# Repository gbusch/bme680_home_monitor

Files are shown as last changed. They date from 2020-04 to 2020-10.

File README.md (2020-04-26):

# Indoor air quality monitoring
From (indoor air quality) measurement to dashboard without any manual configuration.

## Table of contents
* [Goal](#Goal)
  * [Additional technical requirements](#Additional-technical-requirements)
* [Realization](#Realization)
  * [Measuring and sending data with the ESP32](#Measuring-and-sending-data-with-the-ESP32)
  * [Processing, storing, and displaying data on the Raspberry Pi](#Processing,-storing,-and-displaying-data-on-the-Raspberry-Pi)
  * [Compiling the protocol buffers](#Compiling-the-protocol-buffers)
* [Shopping list](#Shopping-list)
* [How to get started](#How-to-get-started)

## Goal
My goal was to monitor temperature, humidity and indoor air quality (IAQ) in our apartment and display it in a dashboard which should be accessible from within our home network.

### Additional technical requirements
Additional requirements, which were mostly not practically necessary but rather added for educational purposes, where:
* communication between microcontroller and Raspberry Pi with MQTT
* MQTT messages are encoded in protocol buffer (protobuf) format
* software on microcontroller should be fully version controlled, including dependencies
* software on Raspberry Pi should be fully version controlled as well, including all configurations, and all software should be started with one command.

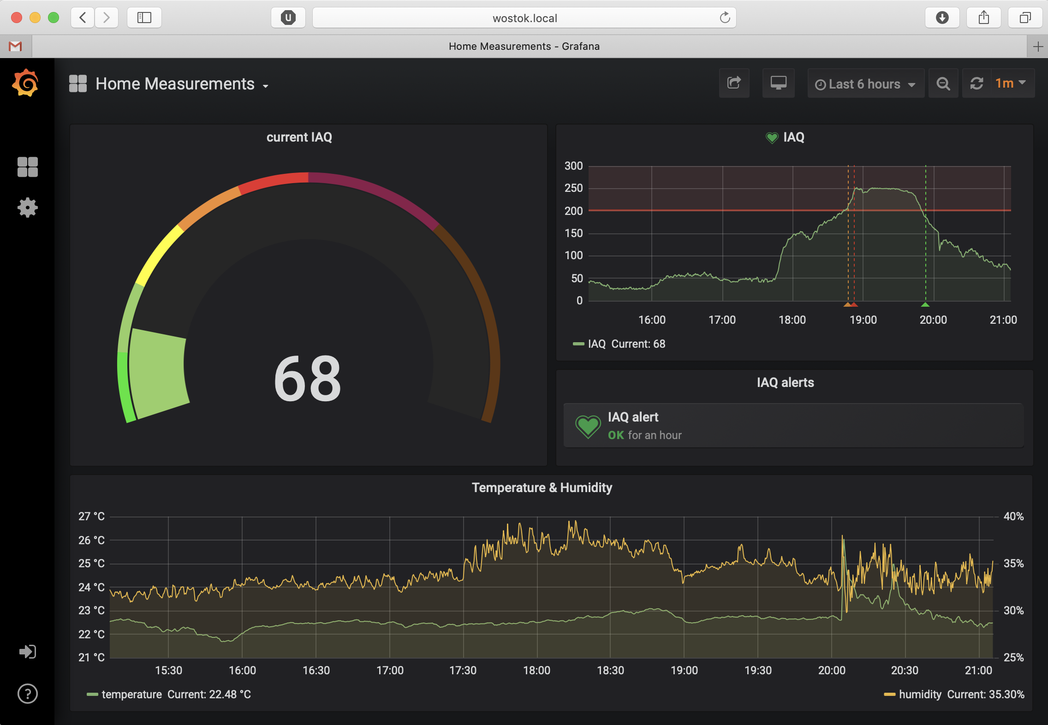
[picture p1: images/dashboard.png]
screenshot of dashboard missing


## Realization
This was realized with a BME680 sensor from Bosch connected to a ESP32 which is a powerful microcontroller with, amongst others, wifi connectivity. The backend and frontend run on a Raspberry Pi 3B+. As frontend we use Grafana which also allows for alerting, for example as Telegram notifications on the smart phone. The Grafana dashboard can be accessed from all devices which are connected to the home wifi network.

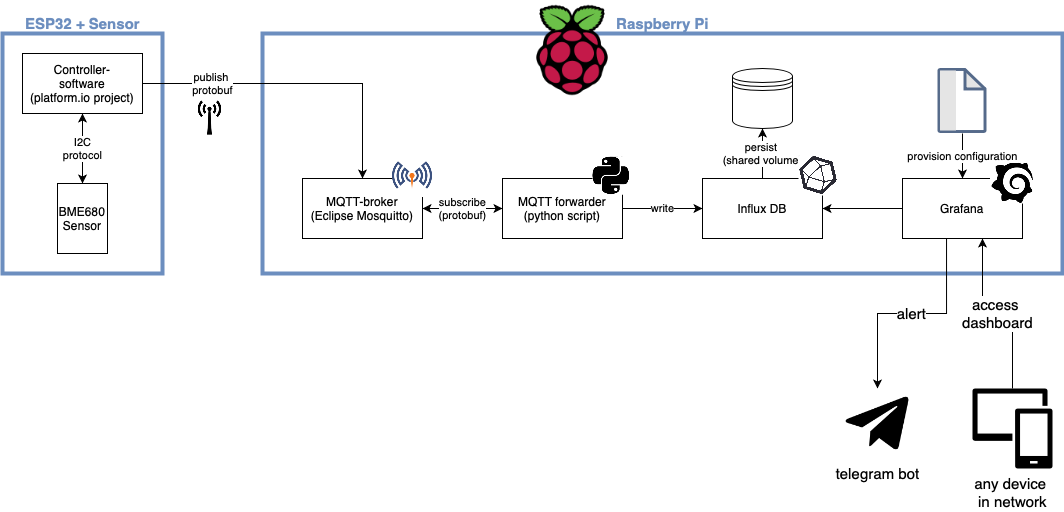
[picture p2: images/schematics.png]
image missing Schematics


### Measuring and sending data with the ESP32
The manufacturer of the BME680 sensor provides a library for several controllers, including the ESP8266/ESP32. In contrast to other open-source libraries for the BME-sensor series, the so-called BSEC library includes a self-calibration of the indoor air quality sensors.

The scripts provided were augmented with additional functionality for this project:
* connection to the home wifi, using the standard wifi library for ESP32
* connection and publishing to an MQTT-broker using the pubsub-client library
* encoding of messages to protocol buffers using the nanopb library (more details on protocol buffers below).

PlatformIO was used to program the ESP32. This platform does not only offer the comfort of an IDE (e.g. code completion) but also dependency management. This is a huge improvement compared to Arduino IDE where dependencies are usually installed manually and stored globally. Here, the dependencies are tracked per project which allows to include them into version control and they are installed automatically when building the project. 

Software for the ESP32 is provided in the [esp32_bme680](./esp32_bme680/) folder, detailed instructions can be found in the associated [README](./esp32_bme680/README.md).

### Processing, storing, and displaying data on the Raspberry Pi
The measurements that the ESP32 sent as protobuf-encoded MQTT messages, are then processed, stored and displayed using different software components:
* Eclipse Mosquitto as MQTT broker. The ESP32 publishes messages to a specific topic. Other programs can now subscribe to this topic and receive the messages. The MQTT broker is accessible within the home network and can be used for other projects as well.
* A MQTT forwarder script. A simple python script that subscribes to the MQTT topic, decodes all received messages and stores them in a database.
* An InfluxDB databse where the measurements are stored. A shared volume ensures that the data is persisted when the docker container is shutdown or restarted.
* Grafana which is a dashboarding and monitoring tool. The data is displayed in a dashboard that is accessible in a browser from all devices in the network. Furthermore, notifications can be sent, in this example via the Telegram messaging app. Grafana offers provisioning which means that all configuration, including the dashboard definition, is provided in files and no manual configuration is necessary. 

All these components are running as Docker containers on the Raspberry Pi. Using docker-compose, the whole stack can be started with one single command. Running them as Docker containers offers many advantages:
* Preconfigured Docker containers are provided for most open-source projects so that no manual installation is necessary.
* Configuration can be documented and version-controlled using the docker-compose file.
* Dependencies are automatically handled.
* Everything can be started (and shut down) with one command.

Software and more detailed instructions on how to set it up on the Raspberry Pi can be found in the directory [raspberrypi](./raspberrypi/) and the corresponding [README](./raspberrypi/README.md).

### Compiling the protocol buffers
As mentioned before, the messages that are sent from the ESP32 are encoded as protocol buffers. Protocol buffers (short: protobuf) are a language- and platform-neutral mechanism for the serialization and deserialization of structured data. They were developed by Google to be simpler, smaller, faster and easier to maintainer than XML, but even surpass JSON in their performance.

While it is considerably easy to define the message format (see [data.proto](esp32_bme680/src/data.proto)), these proto-files then have to be compiled for each language that they should be used with. Support for several languages, including python, is provided with Google's compiler. Support for other languages is added by the community, namely nanopb for embedded devices like our ESP32.

*Good news is: As long as you do not want to change the message format, there is nothing you have to do as the needed compiled files are included in the repo.*

Note that if, for any reason, you want to change the message format, you need to:
* compile it for the ESP32 (with nanopb) and for the MQTT Forwarder (python)
* change the part where the message is encoded in [main.cpp](esp32_bme680/src/main.cpp) and where it is decoded in [python-listener.py](raspberrypi/mqtt-forwarder/python-listener.py)
* delete the existing InfluxDB database or use a new one in case the schema changes in this process.

The base-compiler protoc as well as nanopb can be installed locally. However to avoid trouble with dependencies, it might be worth considering a dockerized version. You can find more information on the docker image and how to use it on [DockerHub](https://hub.docker.com/repository/docker/buschg/protobuf-compiler/general) (you need a DockerHub account) or [GitHub](https://github.com/gbusch/protobuf-compiler).

## Shopping list
Here is a short overview of the parts that you will need:
* The BME680 sensor from Bosch Sensortec. You probably want to get a breakout board. I got the one from BlueDot. A soldering iron was needed to solder the 6-pin header to the board. There might be boards on the market that have the header already attached. Cost: around 20 €. (If you are not interested in indoor air quality but only temperature and humidity you might want to check out the BME280 which is available for less than 5 €.)
* An ESP32 microcontroller. I used the ESP32 Dev Kit C from az-delivery.de but there are many different versions on the market that should work as well. A ESP8266 can also be used but I failed to fully program it with platformIO without any manual modifications. Cost: around 10 €.
* Jumper wires (female-female) to connect ESP32 and sensor.
* A micro-USB charger to power the ESP32.
* A Raspberry Pi with (micro) SD card and power supply. I got an ABOX (now LABISTS) Raspberry Pi 3B+ starter kit which also contained case, power supply, heat sinks and SD card. Cost: around 85 € (A bare Raspberry Pi costs only half, but I recommend to get one proper kit since you can use it for many other projects at the same time as well).

## How to get started
* Get the parts from the shopping list
* Follow [this description](./esp32_bme680/README.md) to connect the sensor and upload the software to the ESP32. Each time serial output is printed, the LED of the ESP32 blinks. For that reason most ```Serial.println()``` are commented out in the script. You might want to use these statements at first for debugging.
* Follow [this description](./raspberrypi/README.md) to setup the Raspberry Pi.
* You can now point your browser to ```http://<address of your raspberry pi>:3000/d/kpBr4Nzgz/home-measurements?orgId=1``` to see your measurements in a dashboard.

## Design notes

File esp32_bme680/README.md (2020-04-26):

# Setting up the sensor and microcontroller

* Install platform.io (instructions can be found on the [project's webpages](https://platformio.org))

* If you use the ESP32 for the first time, you might need to install USB drivers. My ESP32 board uses a CP2102 USB serial communication interface module for which drivers are provided by Silicon Labs.

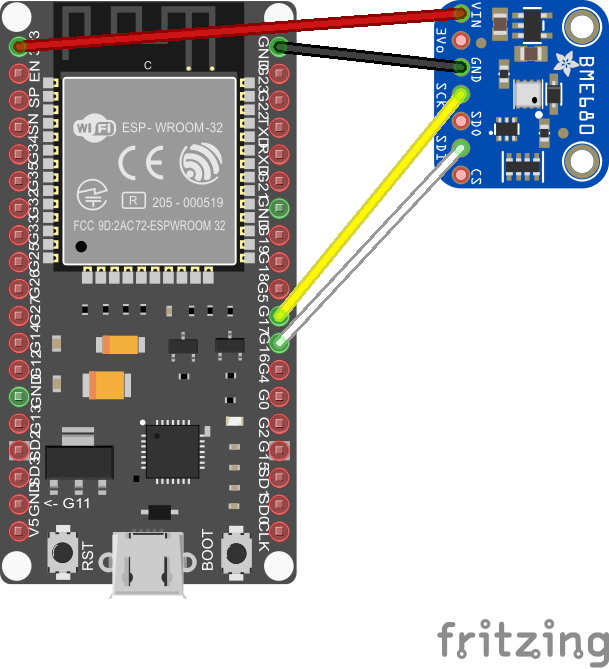
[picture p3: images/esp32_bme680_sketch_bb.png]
image missing sketch
* Connect the sensor and microcontroller as indicated in the sketch. 

* Import the directory esp32_bme680 as a new project into platform.io.

* Create a file include/credentials.h and insert your credentials for wifi and MQTT broker (the address of your raspberry pi). The expected schema is shown in the file [credentials.h.example](include/credentials.h.example).

* You can now upload the project to the ESP32 using platform.io.

*Note: Most software in this folder, including the precompiled library, is provided by Bosch Sensortec and only slightly modified. All rights remain at Bosch Sensortec.*

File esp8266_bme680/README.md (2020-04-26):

# Code for ESP8266 (deprecated)

At first, I used an ESP8266 microcontroller. The code that I used can be found in this directory. However, here the Arduino IDE is used to flash the controller (note the *.ino file). 

I tried to switch to platform.io since this allows to include all dependencies as well. Unfortunately, there was still manual configuration necessary. Namely, the linker script had to be adjusted as described [on the library's Github page](https://github.com/BoschSensortec/BSEC-Arduino-library#4-additional-core-specific-modifications). After many (unsuccessful) tries to include a modified version of this linker script in the project, I decided to switch to an ESP32 where the configuration with platform.io is straight-forward.

If you want to use an ESP8266, these files might help but they will not work straight away. More information on how to get the BSEC software running on ESP8266 can be found [on the library's github page](https://github.com/BoschSensortec/BSEC-Arduino-library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).

Please note that the protobuf message format has changed in the meantime and has to be adjusted (in the mqtt-forwarder).

Also you will have to add your network configuration in [esp8266_bme680.ino]():
```C
const char* ssid = ## your wifi name here ##;
const char* password = ## your wifi password here ##;
const char* mqttServer = ## your MQTT brokers (raspberry pi) address ##;
const int mqttPort = 1883;
```

*Note: Most software in this folder is provided by Bosch Sensortec and only slightly modified. All rights remain at Bosch Sensortec.*

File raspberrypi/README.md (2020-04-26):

# Setting up the Raspberry Pi

## Installation

* Set up your Raspberry Pi with a Linux operating system (e.g. Raspbian) and login (either directly or via ssh). Explaining how to do that is out of scope. However, there are plenty of resources online.

* The following lines have to be executed to install docker. The last line confirms that the installation was successful.
```bash
curl -fsSL get.docker.com -o get-docker.sh && sh get-docker.sh
sudo usermod -aG docker pi
sudo reboot
docker run hello-world
```

* Then install docker-compose. The last line prints out the docker-compose version which confirms a successful installation.
```bash
sudo apt-get install -y python3-pip python3-dev
sudo pip3 install docker-compose
docker-compose --version
```

* You should now clone this repo ```git clone https://github.com/gbusch/bme680_home_monitor.git``` and change to the raspberrypi folder: ```cd bme680_home_monitor/raspberrypi```.

* Now you need to run the build command: ```docker-compose build```. You need to run this command only once and after changes in the mqtt-forwarder.

* Start the docker containers with ```docker-compose up -d```. 

* If you want to stop the containers later, you can do that with ```docker-compose down```.

## Docker containers
The following docker containers will be started:
 
### MQTT-broker (Eclipse Mosquitto)
Eclipse Mosquitto is a light-weight MQTT broker. 
You can use the MQTT broker for other projects as well. Just choose a different topic to publish on.
It will be available in the home network under the address of your Raspberry Pi (since it is in the local network the IP address should start with 192.168.178.*) and port 1883. This is the default port for unencrypted MQTT.

### Database (InfluxDB)
InfluxDB is a database specially suited for timeseries data. The data is stored in the directory ```/var/lib/influxdb```. This folder is mounted to the directory ```./influxdb/data``` on the host machine. This allows to keep data also when the docker-container is shutdown.

### Dashboard (Grafana)
Grafana is an open-source dashboard and monitoring tool. It is accessible from the browser under ```<address of your Raspberry Pi>:3000```. A powerful feature in the newest versions is provisioning. This allows to save the dashboards as well as configuration for data sources and notifications in json and yaml files and provide them to Grafana when the container is started. This way, dashboards can be easily shared and version-controlled together with the project.

The example dashboard will automatically be loaded when the docker containers are started and is accessible in the browser under ```<address of your Raspberry Pi>:3000/d/kpBr4Nzgz/home-measurements?orgId=1```.

#### Changing the dashboard
* Sign in to Grafana using the credentials provided in the [docker-compose.yml](docker-compose.yml) (at the moment admin/secret-password).
* Adjust the dashboard
* Click save. You cannot save a provisioned dashboard from the Grafana UI, instead choose "copy JSON to clipboard". Copy this into the file [./grafana/dashboards/home_measurements.json](./grafana/dashboards/home_measurements.json) and save.
* Next time you restart the container, the new version will be provisioned.

#### Setting up a telegram alert
Grafana also offers alerting and supports many different notification channels. As an example, I configured an alert that is raised whenever the indoor air quality exceeds a value of 200. 

With the following steps, you can configure notifications to Telegram when this alert is raised:

* Create a new bot as described in the [Telegram Documentation](https://core.telegram.org/bots#6-botfather). Note down the bot token.
* Create a telegram group with people that should be alerted and invite the bot to this group.
* Use curl or place this in a browser: ```https://api.telegram.org/bot<TOKEN>/getUpdates```.
* The response returns a json object in which you find the key "chat". Note down the number after "id" (including the dash).
* You can find an example configuration in [./grafana/provisioning/notifiers/telegram.yml.example](./grafana/provisioning/notifiers/telegram.yml.example). Remove the file-ending ".example" and insert bot token and chat id.
* Restart Grafana.

### MQTT forwarder script
This simple python script subscribes to the same topic that the ESP32 publishes to and writes all messages that it receives into the InfluxDB database. The script runs in a Docker container as well so that you do not need to worry about python configuration or the like.

Please note that the first time you use it and whenever you make changes to the script you need to rebuild the container with ```docker-compose build```.

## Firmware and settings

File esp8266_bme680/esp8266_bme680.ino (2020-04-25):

/*
 * Copyright (C) 2017 Robert Bosch. All Rights Reserved. 
 *
 * Disclaimer
 *
 * Common:
 * Bosch Sensortec products are developed for the consumer goods industry. They may only be used
 * within the parameters of the respective valid product data sheet.  Bosch Sensortec products are
 * provided with the express understanding that there is no warranty of fitness for a particular purpose.
 * They are not fit for use in life-sustaining, safety or security sensitive systems or any system or device
 * that may lead to bodily harm or property damage if the system or device malfunctions. In addition,
 * Bosch Sensortec products are not fit for use in products which interact with motor vehicle systems.
 * The resale and/or use of products are at the purchasers own risk and his own responsibility. The
 * examination of fitness for the intended use is the sole responsibility of the Purchaser.
 *
 * The purchaser shall indemnify Bosch Sensortec from all third party claims, including any claims for
 * incidental, or consequential damages, arising from any product use not covered by the parameters of
 * the respective valid product data sheet or not approved by Bosch Sensortec and reimburse Bosch
 * Sensortec for all costs in connection with such claims.
 *
 * The purchaser must monitor the market for the purchased products, particularly with regard to
 * product safety and inform Bosch Sensortec without delay of all security relevant incidents.
 *
 * Engineering Samples are marked with an asterisk (*) or (e). Samples may vary from the valid
 * technical specifications of the product series. They are therefore not intended or fit for resale to third
 * parties or for use in end products. Their sole purpose is internal client testing. The testing of an
 * engineering sample may in no way replace the testing of a product series. Bosch Sensortec
 * assumes no liability for the use of engineering samples. By accepting the engineering samples, the
 * Purchaser agrees to indemnify Bosch Sensortec from all claims arising from the use of engineering
 * samples.
 *
 * Special:
 * This software module (hereinafter called "Software") and any information on application-sheets
 * (hereinafter called "Information") is provided free of charge for the sole purpose to support your
 * application work. The Software and Information is subject to the following terms and conditions:
 *
 * The Software is specifically designed for the exclusive use for Bosch Sensortec products by
 * personnel who have special experience and training. Do not use this Software if you do not have the
 * proper experience or training.
 *
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
 * Bosch Sensortec and their representatives and agents deny any liability for the functional impairment
 * of this Software in terms of fitness, performance and safety. Bosch Sensortec and their
 * representatives and agents shall not be liable for any direct or indirect damages or injury, except as
 * otherwise stipulated in mandatory applicable law.
 *
 * The Information provided is believed to be accurate and reliable. Bosch Sensortec assumes no
 * responsibility for the consequences of use of such Information nor for any infringement of patents or
 * other rights of third parties which may result from its use. No license is granted by implication or
 * otherwise under any patent or patent rights of Bosch. Specifications mentioned in the Information are
 * subject to change without notice.
 *
 * It is not allowed to deliver the source code of the Software to any third party without permission of
 * Bosch Sensortec.
 *
 */

/*!
 * @file bsec_iot_example.ino
 *
 * @brief
 * Example for using of BSEC library in a fixed configuration with the BME680 sensor.
 * This works by running an endless loop in the bsec_iot_loop() function.
 */

/*!
 * @addtogroup bsec_examples BSEC Examples
 * @brief BSEC usage examples
 * @{*/

/**********************************************************************************************************************/
/* header files */
/**********************************************************************************************************************/

#include "bsec_integration.h"
#include <Wire.h>
#include <ESP8266WiFi.h>
#include <PubSubClient.h>

#include "data.pb.h"
#include <pb_common.h>
#include <pb.h>
#include <pb_encode.h>

const char* ssid = ## your wifi name here ##;
const char* password = ## your wifi password here ##;
const char* mqttServer = ## your MQTT brokers (raspberry pi) address ##;
const int mqttPort = 1883;

WiFiClient espClient;
PubSubClient client(espClient);

char tempBuffer[100];

/**********************************************************************************************************************/
/* functions */
/**********************************************************************************************************************/

/*!
 * @brief           Write operation in either Wire or SPI
 *
 * param[in]        dev_addr        Wire or SPI device address
 * param[in]        reg_addr        register address
 * param[in]        reg_data_ptr    pointer to the data to be written
 * param[in]        data_len        number of bytes to be written
 *
 * @return          result of the bus communication function
 */
int8_t bus_write(uint8_t dev_addr, uint8_t reg_addr, uint8_t *reg_data_ptr, uint16_t data_len)
{
    Wire.beginTransmission(dev_addr);
    Wire.write(reg_addr);    /* Set register address to start writing to */
 
    /* Write the data */
    for (int index = 0; index < data_len; index++) {
        Wire.write(reg_data_ptr[index]);
    }
 
    return (int8_t)Wire.endTransmission();
}

/*!
 * @brief           Read operation in either Wire or SPI
 *
 * param[in]        dev_addr        Wire or SPI device address
 * param[in]        reg_addr        register address
 * param[out]       reg_data_ptr    pointer to the memory to be used to store the read data
 * param[in]        data_len        number of bytes to be read
 *
 * @return          result of the bus communication function
 */
int8_t bus_read(uint8_t dev_addr, uint8_t reg_addr, uint8_t *reg_data_ptr, uint16_t data_len)
{
    int8_t comResult = 0;
    Wire.beginTransmission(dev_addr);
    Wire.write(reg_addr);                    /* Set register address to start reading from */
    comResult = Wire.endTransmission();
 
    delayMicroseconds(150);                 /* Precautionary response delay */
    Wire.requestFrom(dev_addr, (uint8_t)data_len);    /* Request data */
 
    int index = 0;
    while (Wire.available())  /* The slave device may send less than requested (burst read) */
    {
        reg_data_ptr[index] = Wire.read();
        index++;
    }
 
    return comResult;
}

/*!
 * @brief           System specific implementation of sleep function
 *
 * @param[in]       t_ms    time in milliseconds
 *
 * @return          none
 */
void sleep(uint32_t t_ms)
{
    delay(t_ms);
}

/*!
 * @brief           Capture the system time in microseconds
 *
 * @return          system_current_time    current system timestamp in microseconds
 */
int64_t get_timestamp_us()
{
    return (int64_t) millis() * 1000;
}

/*!
 * @brief           Handling of the ready outputs
 *
 * @param[in]       timestamp       time in nanoseconds
 * @param[in]       iaq             IAQ signal
 * @param[in]       iaq_accuracy    accuracy of IAQ signal
 * @param[in]       temperature     temperature signal
 * @param[in]       humidity        humidity signal
 * @param[in]       pressure        pressure signal
 * @param[in]       raw_temperature raw temperature signal
 * @param[in]       raw_humidity    raw humidity signal
 * @param[in]       gas             raw gas sensor signal
 * @param[in]       bsec_status     value returned by the bsec_do_steps() call
 *
 * @return          none
 */
void output_ready(int64_t timestamp, float iaq, uint8_t iaq_accuracy, float temperature, float humidity,
     float pressure, float raw_temperature, float raw_humidity, float gas, bsec_library_return_t bsec_status)
{
    if (!client.connected()) {
        reconnect();
    }
    client.loop();
    Serial.print("[");
    Serial.print(timestamp/1e6);
    Serial.print("] T: ");
    Serial.print(temperature);
    Serial.print("| rH: ");
    Serial.print(humidity);
    Serial.print("| IAQ: ");
    Serial.print(iaq);
    Serial.print(" (");
    Serial.print(iaq_accuracy);
    Serial.println(")");

    pb_WeatherData data;
    data.deviceId = 1;
    data.temperature = temperature;
    data.humidity = humidity;
    data.pressure = pressure/100.;
    data.IAQ = iaq;
    data.iaq_accuracy = iaq_accuracy;

    uint8_t buffer[128];
    pb_ostream_t stream = pb_ostream_from_buffer(buffer, 128);

    if (!pb_encode(&stream, pb_WeatherData_fields, &data)){
        Serial.println("failed to encode temp proto");
    } else {
        client.publish("/weather/bedroom", buffer, stream.bytes_written);
    }
}

/*!
 * @brief           Load previous library state from non-volatile memory
 *
 * @param[in,out]   state_buffer    buffer to hold the loaded state string
 * @param[in]       n_buffer        size of the allocated state buffer
 *
 * @return          number of bytes copied to state_buffer
 */
uint32_t state_load(uint8_t *state_buffer, uint32_t n_buffer)
{
    // ...
    // Load a previous library state from non-volatile memory, if available.
    //
    // Return zero if loading was unsuccessful or no state was available, 
    // otherwise return length of loaded state string.
    // ...
    return 0;
}

/*!
 * @brief           Save library state to non-volatile memory
 *
 * @param[in]       state_buffer    buffer holding the state to be stored
 * @param[in]       length          length of the state string to be stored
 *
 * @return          none
 */
void state_save(const uint8_t *state_buffer, uint32_t length)
{
    // ...
    // Save the string some form of non-volatile memory, if possible.
    // ...
}

/*!
 * @brief           Load library config from non-volatile memory
 *
 * @param[in,out]   config_buffer    buffer to hold the loaded state string
 * @param[in]       n_buffer        size of the allocated state buffer
 *
 * @return          number of bytes copied to config_buffer
 */
uint32_t config_load(uint8_t *config_buffer, uint32_t n_buffer)
{
    // ...
    // Load a library config from non-volatile memory, if available.
    //
    // Return zero if loading was unsuccessful or no config was available, 
    // otherwise return length of loaded config string.
    // ...
    return 0;
}

/*!
 * @brief       Main function which configures BSEC library and then reads and processes the data from sensor based
 *              on timer ticks
 *
 * @return      result of the processing
 */
void setup()
{
    return_values_init ret;

    /* Init I2C and serial communication */
    Wire.begin(0,4);
    Serial.begin(115200);
    WiFi.begin(ssid, password);
    Serial.println("Connecting to Wifi");
    while (WiFi.status() != WL_CONNECTED) {
        delay(500);
        Serial.print(".");
    }
    Serial.println("Connented to Wifi with local IP: ");
    Serial.println(WiFi.localIP());

    client.setServer(mqttServer, mqttPort);

  
    /* Call to the function which initializes the BSEC library 
     * Switch on low-power mode and provide no temperature offset */
    ret = bsec_iot_init(BSEC_SAMPLE_RATE_LP, 0.0f, bus_write, bus_read, sleep, state_load, config_load);
    if (ret.bme680_status)
    {
        /* Could not intialize BME680 */
        Serial.println("Error while initializing BME680");
        return;
    }
    else if (ret.bsec_status)
    {
        /* Could not intialize BSEC library */
        Serial.println("Error while initializing BSEC library");
        return;
    }
    
    /* Call to endless loop function which reads and processes data based on sensor settings */
    /* State is saved every 10.000 samples, which means every 10.000 * 3 secs = 500 minutes  */
    bsec_iot_loop(sleep, get_timestamp_us, output_ready, state_save, 10000);
}

void loop()
{
}

void reconnect() {
    while (!client.connected()) {
        if (!client.connect("ESP8266Client")) {
            Serial.print("failed, rc=");
            Serial.print(client.state());
            Serial.println(" retrying in 5 seconds");
            delay(500);
        }
    }
}
/*! @}*/

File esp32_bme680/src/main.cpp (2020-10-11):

/* 
 * Example script for Bosch BSEC library
 * modified to publish data via MQTT
 * 
 * Copyright (C) 2017 Robert Bosch. All Rights Reserved. 
 */

#include <Arduino.h>

#include "bsec.h"
#include "credentials.h"

#include "WiFi.h"
#include <PubSubClient.h>

#include "data.pb.h"
#include <pb.h>
#include <pb_encode.h>

// Helper functions declarations
void checkIaqSensorStatus(void);
void mqtt_reconnect(void);

// Create an object of the class Bsec
Bsec iaqSensor;

String output;
int Nmeasure;

WiFiClient espClient;
PubSubClient client(espClient);

//for watchdog
#include "esp_system.h"
const int loopTimeCtl = 0;
hw_timer_t *timer = NULL;
const int watchdogTimeoutUs = 30000000; //in usec

void IRAM_ATTR resetModule()
{
  ets_printf("reboot\n");
  esp_restart();
}

void feedWatchdog()
{
  timerWrite(timer, 0); //reset timer (feed watchdog)
}

// Entry point for the example
void setup(void)
{
  Serial.begin(115200);
  Wire.begin(16, 17);

  //setup watchdog early to allow trigger even during setup
  timer = timerBegin(0, 80, true); //timer 0, div 80
  timerAttachInterrupt(timer, &resetModule, true);
  timerAlarmWrite(timer, watchdogTimeoutUs, false); //set time in us
  timerAlarmEnable(timer);                          //enable interrupt

  Serial.print("## Connecting to WiFi ##");
  WiFi.begin(ssid, password);

  while (WiFi.status() != WL_CONNECTED)
  {
    delay(500);
    Serial.print(".");
  }
  Serial.println("Connented to Wifi with local IP: ");
  Serial.println(WiFi.localIP());

  client.setServer(mqttServer, mqttPort);

  iaqSensor.begin(BME680_I2C_ADDR_SECONDARY, Wire);
  output = "\nBSEC library version " + String(iaqSensor.version.major) + "." + String(iaqSensor.version.minor) + "." + String(iaqSensor.version.major_bugfix) + "." + String(iaqSensor.version.minor_bugfix);
  Serial.println(output);
  checkIaqSensorStatus();

  bsec_virtual_sensor_t sensorList[10] = {
      BSEC_OUTPUT_RAW_TEMPERATURE,
      BSEC_OUTPUT_RAW_PRESSURE,
      BSEC_OUTPUT_RAW_HUMIDITY,
      BSEC_OUTPUT_RAW_GAS,
      BSEC_OUTPUT_IAQ,
      BSEC_OUTPUT_STATIC_IAQ,
      BSEC_OUTPUT_CO2_EQUIVALENT,
      BSEC_OUTPUT_BREATH_VOC_EQUIVALENT,
      BSEC_OUTPUT_SENSOR_HEAT_COMPENSATED_TEMPERATURE,
      BSEC_OUTPUT_SENSOR_HEAT_COMPENSATED_HUMIDITY,
  };

  iaqSensor.updateSubscription(sensorList, 10, BSEC_SAMPLE_RATE_LP);
  checkIaqSensorStatus();

  // Print the header
  output = "Timestamp [ms], raw temperature [°C], pressure [hPa], raw relative humidity [%], gas [Ohm], IAQ, IAQ accuracy, temperature [°C], relative humidity [%], Static IAQ, CO2 equivalent, breath VOC equivalent";
  Serial.println(output);
}

// Function that is looped forever
void loop(void)
{
  unsigned long time_trigger = millis();
  if (iaqSensor.run())
  { // If new data is available
    output = String(time_trigger);
    output += ", " + String(iaqSensor.rawTemperature);
    output += ", " + String(iaqSensor.pressure);
    output += ", " + String(iaqSensor.rawHumidity);
    output += ", " + String(iaqSensor.gasResistance);
    output += ", " + String(iaqSensor.iaq);
    output += ", " + String(iaqSensor.iaqAccuracy);
    output += ", " + String(iaqSensor.temperature);
    output += ", " + String(iaqSensor.humidity);
    output += ", " + String(iaqSensor.staticIaq);
    output += ", " + String(iaqSensor.co2Equivalent);
    output += ", " + String(iaqSensor.breathVocEquivalent);
    // onboard LED blinks at every serial print, this is annoying, therefore commented out here.
    // Serial.println(output);
    Nmeasure++;

    if (Nmeasure == 5)
    {
      if (!client.connected())
      {
        delay(3000);
        mqtt_reconnect();
      }

      WeatherData data = WeatherData_init_zero;
      data.deviceId = 1;
      data.temperature = iaqSensor.temperature;
      data.humidity = iaqSensor.humidity;
      data.pressure = iaqSensor.pressure / 100.;
      data.IAQ = iaqSensor.iaq;
      data.iaq_accuracy = iaqSensor.iaqAccuracy;
      data.CO2 = iaqSensor.co2Equivalent;
      data.breath_VOC = iaqSensor.breathVocEquivalent;

      uint8_t buffer[64];
      pb_ostream_t stream = pb_ostream_from_buffer(buffer, sizeof(buffer));

      if (!pb_encode(&stream, WeatherData_fields, &data))
      {
        Serial.println("failed to encode temp proto");
      }
      else
      {
        client.publish("/weather/bedroom", buffer, stream.bytes_written);
      }
      Nmeasure = 0;
    }
  }
  else
  {
    checkIaqSensorStatus();
  }

  sleep(3);
}

// Helper function definitions
void checkIaqSensorStatus(void)
{
  if (iaqSensor.status != BSEC_OK)
  {
    if (iaqSensor.status < BSEC_OK)
    {
      output = "BSEC error code : " + String(iaqSensor.status);
      Serial.println(output);
    }
    else
    {
      output = "BSEC warning code : " + String(iaqSensor.status);
      Serial.println(output);
    }
  }

  if (iaqSensor.bme680Status != BME680_OK)
  {
    if (iaqSensor.bme680Status < BME680_OK)
    {
      output = "BME680 error code : " + String(iaqSensor.bme680Status);
      Serial.println(output);
    }
    else
    {
      output = "BME680 warning code : " + String(iaqSensor.bme680Status);
      Serial.println(output);
    }
  }
}

void mqtt_reconnect(void)
{
  while (!client.connected())
  {
    if (!client.connect("ESP32Client"))
    {
      Serial.print("failed, rc=");
      Serial.print(client.state());
      Serial.println(" retrying in 5 seconds");
      delay(500);
    }
  }
}

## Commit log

2020-04-05 change mqtt topic and rename folder because arduino compiler wants it
2020-04-18 add scripts for esp32
2020-04-25 start readme and add schematics
2020-04-25 doc for microcontrollers
    [esp32_bme680_sketch.fzz]
2020-04-25 insert screenshot, remove credentials
2020-04-26 esp32 in main docu
2020-10-11 add watchdog for reset
    [main.cpp]
